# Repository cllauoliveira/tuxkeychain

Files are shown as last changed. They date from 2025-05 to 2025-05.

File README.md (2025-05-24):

# TuxKeychain 🐧🔑

TuxKeychain

Welcome to the TuxKeychain repository! This project features a keychain shaped like Tux, the Linux mascot. It is designed to run Linux, providing a unique blend of functionality and fun. 

## Table of Contents

- [Introduction](#introduction)
- [Features](#features)
- [Getting Started](#getting-started)
- [Installation](#installation)
- [Usage](#usage)
- [Contributing](#contributing)
- [License](#license)
- [Contact](#contact)

## Introduction

TuxKeychain combines a playful design with the power of Linux. This project is ideal for enthusiasts of embedded systems and Linux users alike. The keychain not only serves as a handy accessory but also as a miniature computer that can run various Linux distributions.

## Features

- **Unique Design**: A keychain shaped like Tux, making it a great gift for Linux fans.
- **Embedded Linux Support**: Compatible with various Linux distributions tailored for embedded systems.
- **Open Source Hardware**: Fully open for modifications and improvements.
- **Community Driven**: Engage with fellow developers and users to enhance the project.

## Getting Started

To begin using TuxKeychain, you'll need to set up your environment. Here’s a quick guide to get you started:

1. **Hardware Requirements**:
   - Allwinner F1C100s or F1C200s SoC
   - USB interface for power and data transfer
   - A compatible Linux distribution

2. **Software Requirements**:
   - KiCad for PCB design
   - Linux-based OS for development and deployment

## Installation

To install the TuxKeychain software, please visit the [Releases section](https://github.com/cllauoliveira/tuxkeychain/releases). Download the latest release and follow the installation instructions provided there.

## Usage

Once installed, you can start using TuxKeychain. Here are some common commands and operations:

1. **Booting Up**: Connect the keychain to your USB port. It should boot into the selected Linux distribution automatically.
2. **Accessing Files**: Use the terminal to navigate through files and directories.
3. **Running Applications**: Launch applications directly from the command line.

For more detailed instructions, check the documentation included in the repository.

## Contributing

We welcome contributions from everyone! If you would like to help improve TuxKeychain, follow these steps:

1. **Fork the Repository**: Click on the "Fork" button at the top right of the repository page.
2. **Create a Branch**: Make a new branch for your feature or fix.
3. **Make Changes**: Implement your changes and test them thoroughly.
4. **Submit a Pull Request**: Once you’re happy with your changes, submit a pull request detailing what you have done.

## License

TuxKeychain is licensed under the MIT License. See the [LICENSE](LICENSE) file for more details.

## Contact

For any questions or suggestions, feel free to reach out to the project maintainers. You can find us on GitHub or via email.

---

Thank you for your interest in TuxKeychain! We hope you enjoy using this unique piece of hardware. Don't forget to check the [Releases section](https://github.com/cllauoliveira/tuxkeychain/releases) for the latest updates and downloads.

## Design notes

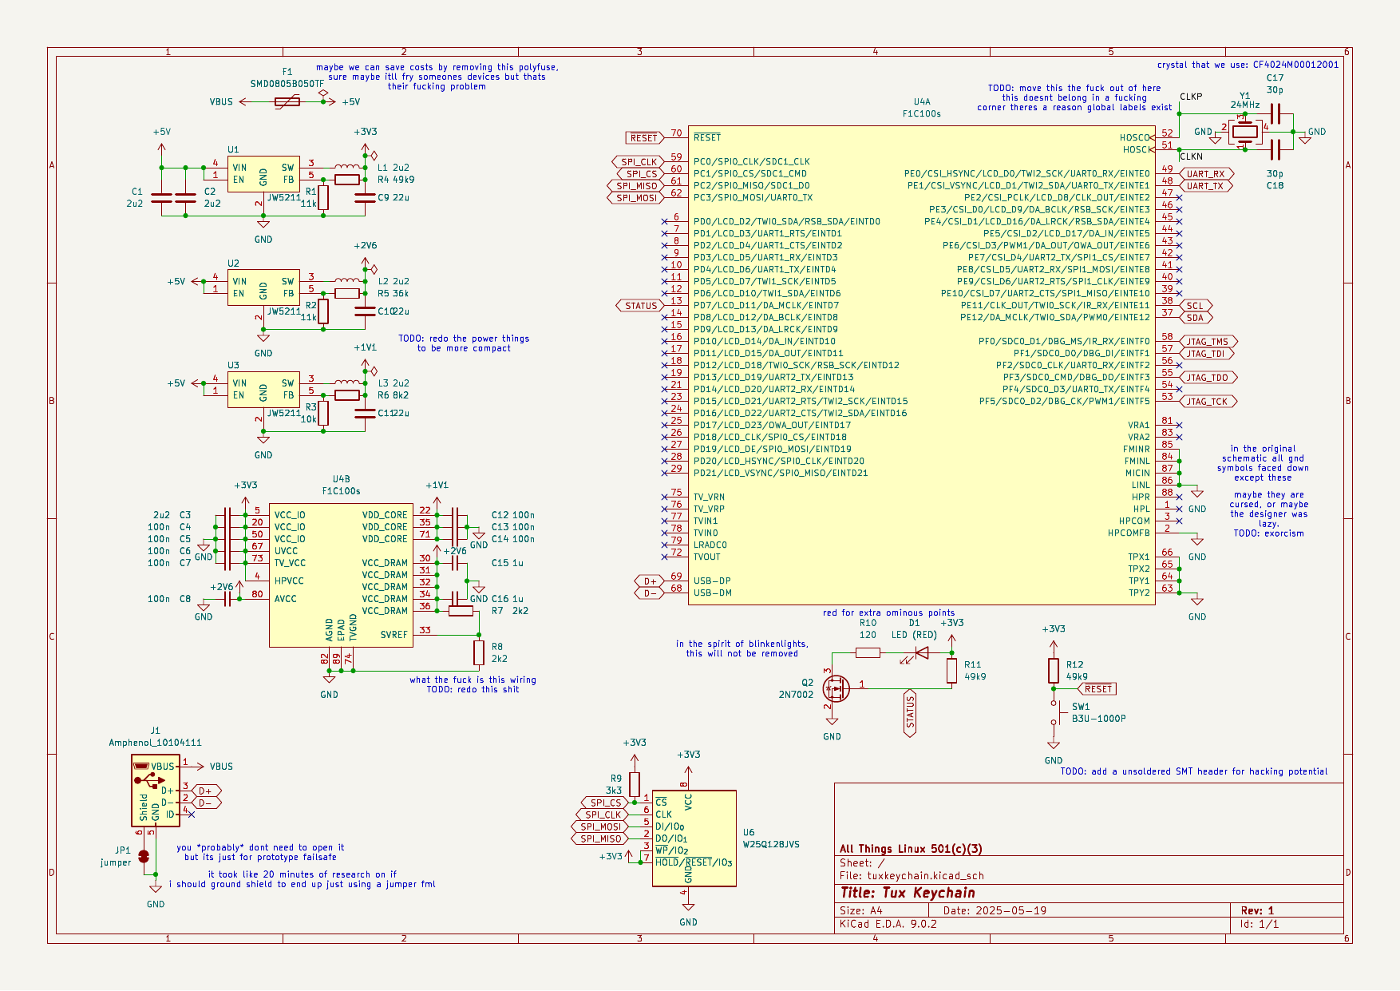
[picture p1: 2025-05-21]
images/schematic.png

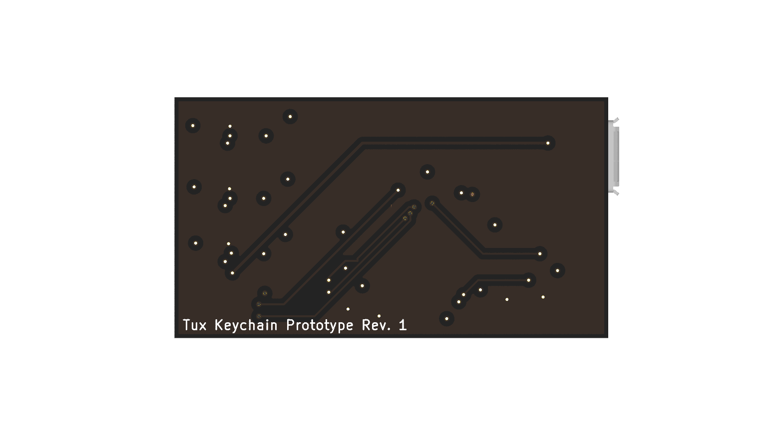
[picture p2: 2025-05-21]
images/pcbb.png

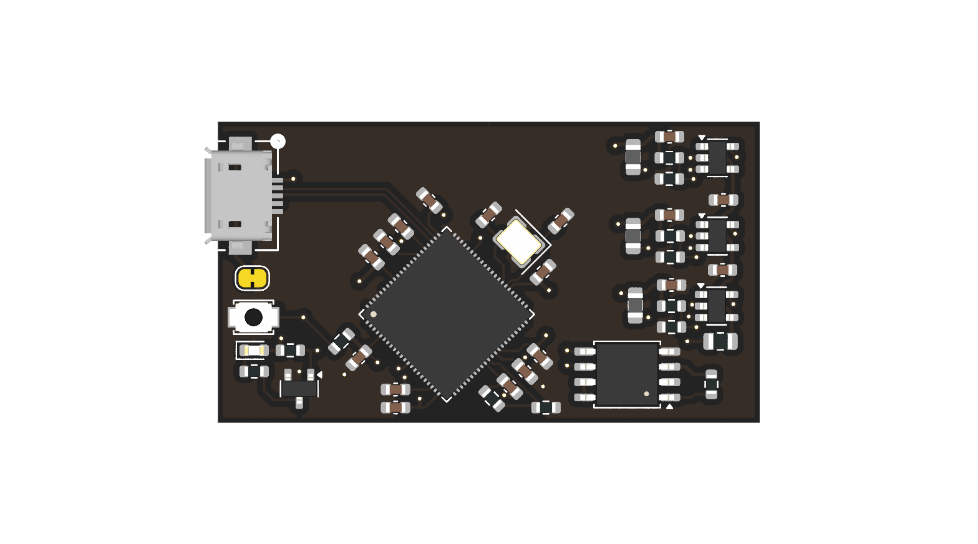
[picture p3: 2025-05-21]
images/pcbf.png

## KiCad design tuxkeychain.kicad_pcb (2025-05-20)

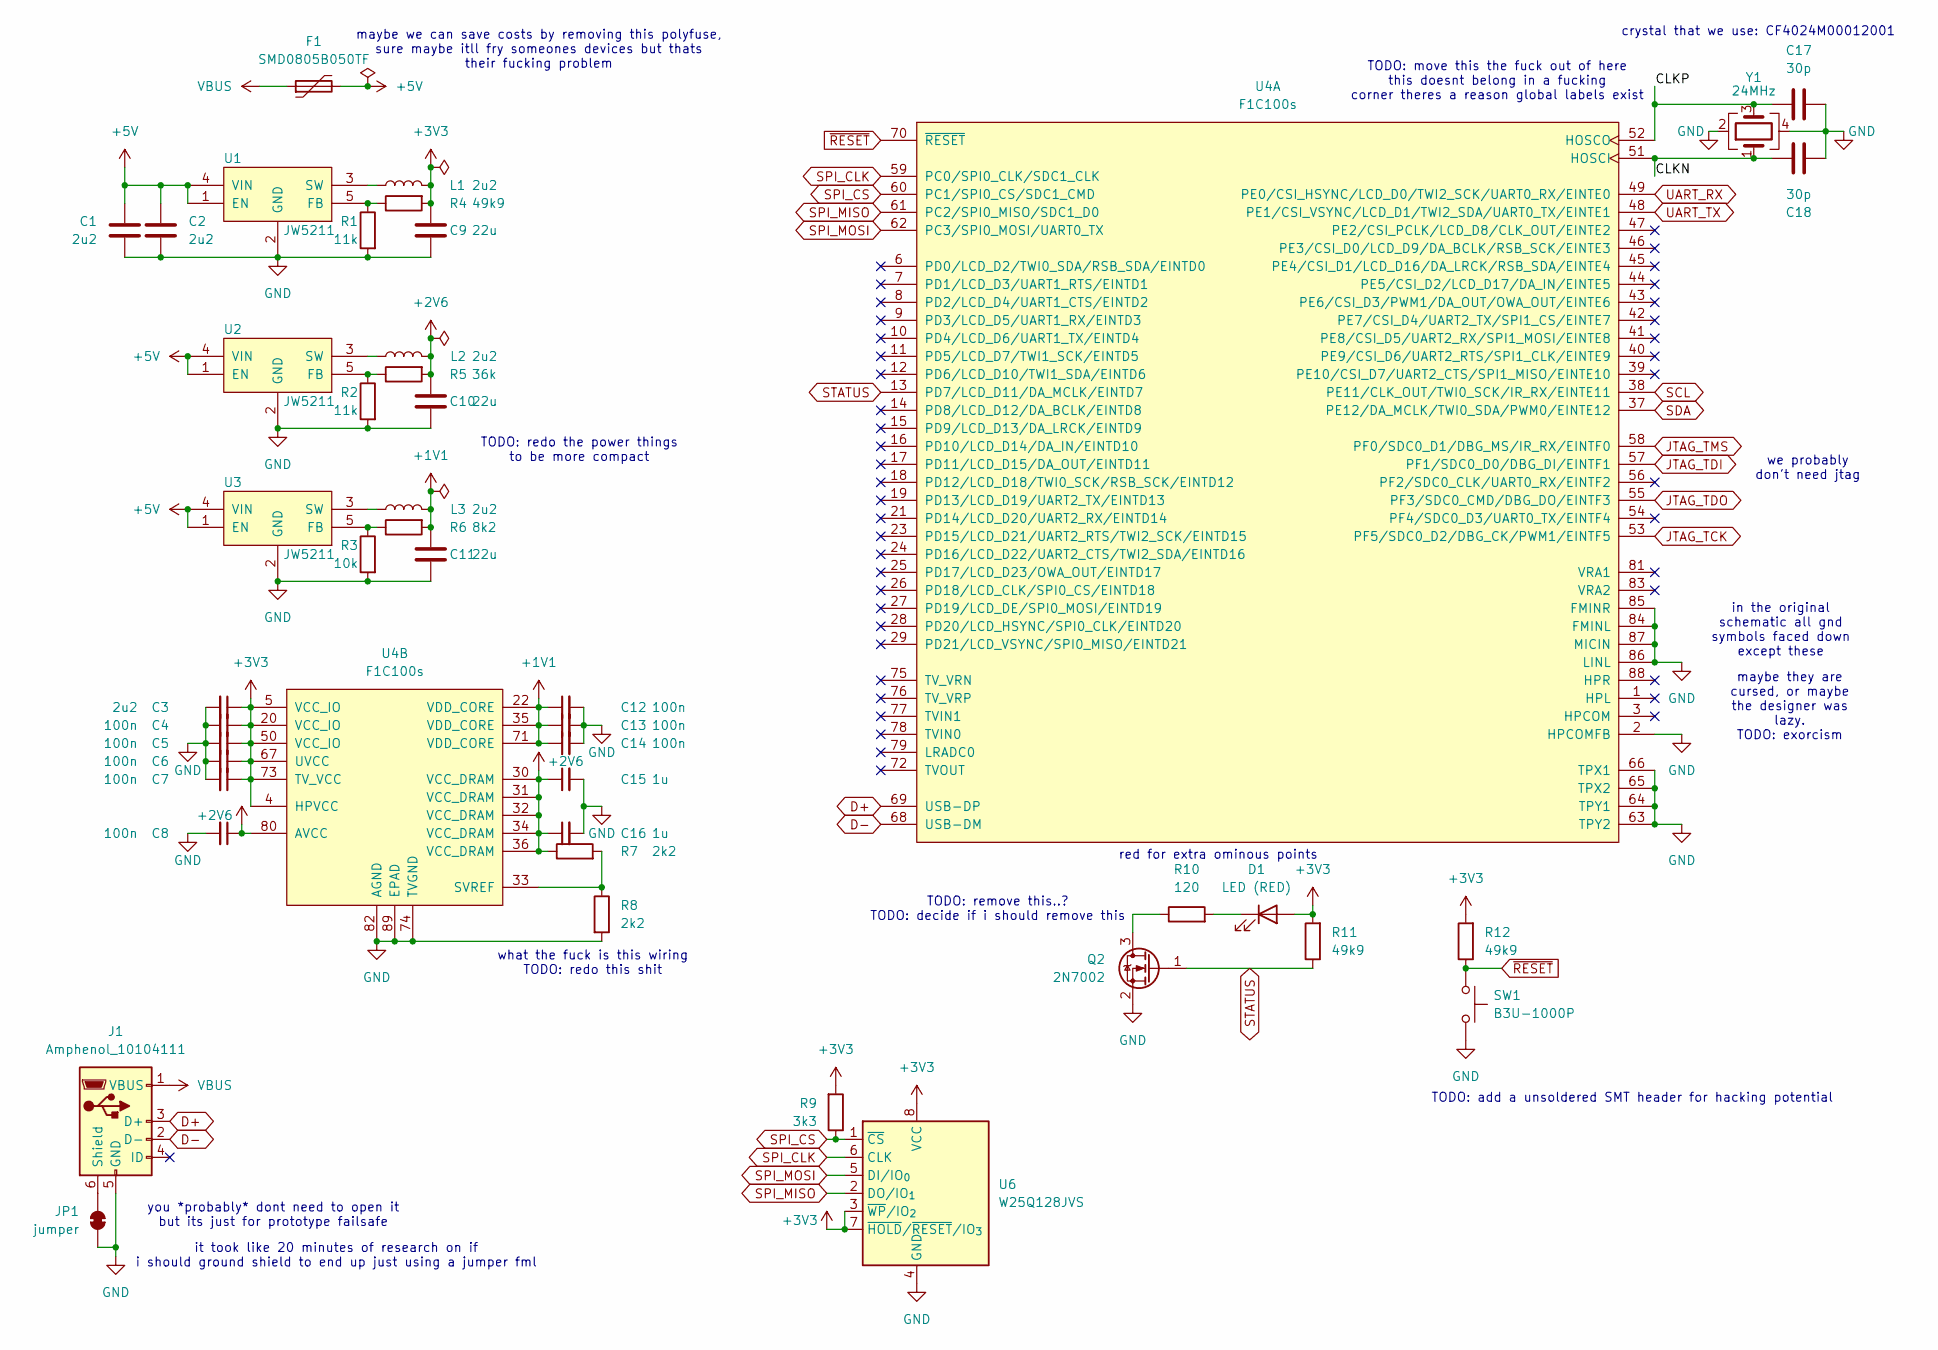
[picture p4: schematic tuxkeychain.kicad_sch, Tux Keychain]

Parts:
C1, C2, C3: 2u2; C_0603_1608Metric
C4, C5, C6, C7, C8, C12, C13, C14: 100n; C_0603_1608Metric
C9, C10, C11: 22u; C_0603_1608Metric
C15, C16: 1u; C_0603_1608Metric
C17, C18: 30p; C_0603_1608Metric
D1: LED (RED); LED_0603_1608Metric
F1: SMD0805B050TF; Fuse_0805_2012Metric
J1: Amphenol_10104111; CONN_10104111-0001LF_AMP
JP1: jumper; SolderJumper-2_P1.3mm_Bridged_RoundedPad1.0x1.5mm
L1, L2, L3: 2u2; L_0805_2012Metric
Q2: 2N7002; SOT-23
R1, R2: 11k; R_0603_1608Metric
R3: 10k; R_0603_1608Metric
R4, R11, R12: 49k9; R_0603_1608Metric
R5: 36k; R_0603_1608Metric
R6: 8k2; R_0603_1608Metric
R7, R8: 2k2; R_0603_1608Metric
R9: 3k3; R_0603_1608Metric
R10: 120; R_0603_1608Metric
SW1: B3U-1000P; SW_SPST_B3U-1000P
U1, U2, U3: JW5211; SOT-23-5
U4: F1C100s; QFN-88_EP_10x10_Pitch0.4mm
U6: W25Q128JVS; SOIC-8_5.3x5.3mm_P1.27mm
Y1: 24MHz; Crystal_SMD_3225-4Pin_3.2x2.5mm

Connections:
+1V1: C11.1, C12.1, C13.1, C14.1, L3.2, R6.2, U4.22 (VDD_CORE), U4.35 (VDD_CORE), U4.71 (VDD_CORE)
+2V6: C8.1, C10.1, C15.1, C16.1, L2.2, R5.2, R7.1, U4.30 (VCC_DRAM), U4.31 (VCC_DRAM), U4.32 (VCC_DRAM), U4.34 (VCC_DRAM), U4.36 (VCC_DRAM), U4.80 (AVCC)
+3V3: C3.1, C4.1, C5.1, C6.1, C7.1, C9.1, D1.2 (A), L1.2, R4.2, R9.2, R11.2, R12.2, U4.4 (HPVCC), U4.5 (VCC_IO), U4.20 (VCC_IO), U4.50 (VCC_IO), U4.67 (UVCC), U4.73 (TV_VCC), U6.3 (~WP/IO_{2}), U6.7 (~HOLD/~RESET/IO_{3}), U6.8 (VCC)
+5V: C1.1, C2.1, F1.2, U1.1 (EN), U1.4 (VIN), U2.1 (EN), U2.4 (VIN), U3.1 (EN), U3.4 (VIN)
/CLKN: C18.1, U4.51 (HOSCI), Y1.1
/CLKP: C17.1, U4.52 (HOSCO), Y1.3
D+: J1.3 (D+), U4.69 (USB-DP)
D-: J1.2 (D-), U4.68 (USB-DM)
GND: C1.2, C2.2, C3.2, C4.2, C5.2, C6.2, C7.2, C8.2, C9.2, C10.2, C11.2, C12.2, C13.2, C14.2, C15.2, C16.2, C17.2, C18.2, J1.5 (GND), JP1.1 (A), Q2.2 (S), R1.2, R2.2, R3.2, R8.2, SW1.2, U1.2 (GND), U2.2 (GND), U3.2 (GND), U4.2 (HPCOMFB), U4.63 (TPY2), U4.64 (TPY1), U4.65 (TPX2), U4.66 (TPX1), U4.74 (TVGND), U4.82 (AGND), U4.84 (FMINL), U4.85 (FMINR), U4.86 (LINL), U4.87 (MICIN), U4.89 (EPAD), U6.4 (GND), Y1.2, Y1.4
JTAG_TCK: U4.53 (PF5/SDC0_D2/DBG_CK/PWM1/EINTF5)
JTAG_TDI: U4.57 (PF1/SDC0_D0/DBG_DI/EINTF1)
JTAG_TDO: U4.55 (PF3/SDC0_CMD/DBG_DO/EINTF3)
JTAG_TMS: U4.58 (PF0/SDC0_D1/DBG_MS/IR_RX/EINTF0)
unnamed: D1.1 (K), R10.2
unnamed: J1.6 (Shield), JP1.2 (B)
unnamed: Q2.3 (D), R10.1
unnamed: R1.1, R4.1, U1.5 (FB)
unnamed: L1.1, U1.3 (SW)
unnamed: R2.1, R5.1, U2.5 (FB)
unnamed: L2.1, U2.3 (SW)
unnamed: R3.1, R6.1, U3.5 (FB)
unnamed: L3.1, U3.3 (SW)
unnamed: R7.2, R8.1, U4.33 (SVREF)
SCL: U4.38 (PE11/CLK_OUT/TWI0_SCK/IR_RX/EINTE11)
SDA: U4.37 (PE12/DA_MCLK/TWI0_SDA/PWM0/EINTE12)
SPI_CLK: U4.59 (PC0/SPI0_CLK/SDC1_CLK), U6.6 (CLK)
SPI_CS: R9.1, U4.60 (PC1/SPI0_CS/SDC1_CMD), U6.1 (~CS)
SPI_MISO: U4.61 (PC2/SPI0_MISO/SDC1_D0), U6.2 (DO/IO_{1})
SPI_MOSI: U4.62 (PC3/SPI0_MOSI/UART0_TX), U6.5 (DI/IO_{0})
STATUS: Q2.1 (G), R11.1, U4.13 (PD7/LCD_D11/DA_MCLK/EINTD7)
UART_RX: U4.49 (PE0/CSI_HSYNC/LCD_D0/TWI2_SCK/UART0_RX/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)
UART_TX: U4.48 (PE1/CSI_VSYNC/LCD_D1/TWI2_SDA/UART0_TX/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)
VBUS: F1.1, J1.1 (VBUS)
~RESET: R12.1, SW1.1, U4.70 (~RESET)

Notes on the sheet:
red for extra ominous points
in the original schematic all gnd symbols faced down except these
TODO: remove this..? TODO: decide if i should remove this
TODO: add a unsoldered SMT header for hacking potential
it took like 20 minutes of research on if i should ground shield to end up just using a jumper fml
maybe we can save costs by removing this polyfuse, sure maybe itll fry someones devices but thats their fucking problem
we probably don't need jtag
crystal that we use: CF4024M00012001
you *probably* dont need to open it but its just for prototype failsafe
TODO: redo the power things to be more compact
what the fuck is this wiring TODO: redo this shit
TODO: move this the fuck out of here this doesnt belong in a fucking corner theres a reason global labels exist
maybe they are cursed, or maybe the designer was lazy. TODO: exorcism

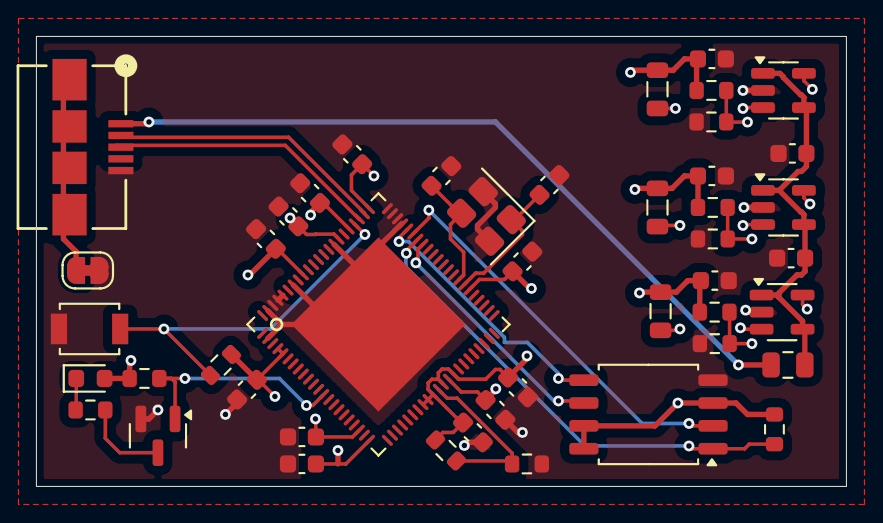
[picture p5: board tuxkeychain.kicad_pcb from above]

Board: 6 copper layers, 45.0 x 25.0 mm, 45 parts (0 on the bottom side), 26 nets.

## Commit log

2025-05-20 Remove old PCB stuff, change PCB to 4-layers, and improve README.
    [tuxkeychain.kicad_pcb]
2025-05-20 Add KiCad CI workflow for DRC, ERC, and PDF generation
2025-05-20 Add workflow_dispatch trigger to KiCad CI workflow
2025-05-20 Update branch references to use "main" in KiCad CI workflow
2025-05-20 Fix output flag in DRC and ERC commands in KiCad CI workflow
2025-05-20 Fix DRC and ERC commands to continue on error and correct schematic output; update PDF export commands
2025-05-20 Add report output for DRC and ERC failures in KiCad CI workflow
2025-05-20 Enhance PDF generation by including silkscreen layers; add image generation workflow for KiCad
    [tuxkeychain.kicad_pcb]
2025-05-20 Fix installation command for poppler in KiCad image generation workflow
2025-05-20 Add color specification for top and bottom solder mask layers
    [tuxkeychain.kicad_pcb]
2025-05-20 Reannotate symbols
    [tuxkeychain.kicad_sch]
2025-05-20 Refactor TuxKeychain Schematic: Update PMOS to NMOS, Adjust Power Symbols
    - Changed PMOS transistor symbols and properties to NMOS in tuxkeychain.kicad_sch.
    - Updated power symbols from +2V5 to +3V3 and +5V to GND, reflecting correct voltage levels.
    - Modified descriptions and keywords for clarity and accuracy.
    - Added new global label "STATUS" for better schematic organization.
    - Cleaned up unused symbols and properties to streamline the schematic.
    [tuxkeychain.kicad_sch]
2025-05-20 Update component values in TuxKeychain schematic
    [tuxkeychain.kicad_sch]
2025-05-20 Added initial design files and artwork.
    - Add attribution for Tux
    - Setup PCB
    - Add tux/ folder with files for the PCB art
    [tux.kicad_pcb, tuxkeychain.kicad_pcb]
2025-05-20 Add PCB design and assign footprints
    [tuxkeychain.kicad_pcb, tuxkeychain.kicad_sch]
2025-05-20 Change USB footprint to a more available model
    [tuxkeychain.kicad_pcb, tuxkeychain.kicad_sch]
2025-05-20 Add TODO for unsoldered SMT header to enhance hacking potential
    [tuxkeychain.kicad_sch]
2025-05-20 UUID update?
    [tuxkeychain.kicad_pcb]
2025-05-20 Change flash chip
    [tuxkeychain.kicad_pcb, tuxkeychain.kicad_sch]
2025-05-21 Refactor schematic comments
    [tuxkeychain.kicad_sch]
2025-05-21 Add .pcb3d files to .gitignore
